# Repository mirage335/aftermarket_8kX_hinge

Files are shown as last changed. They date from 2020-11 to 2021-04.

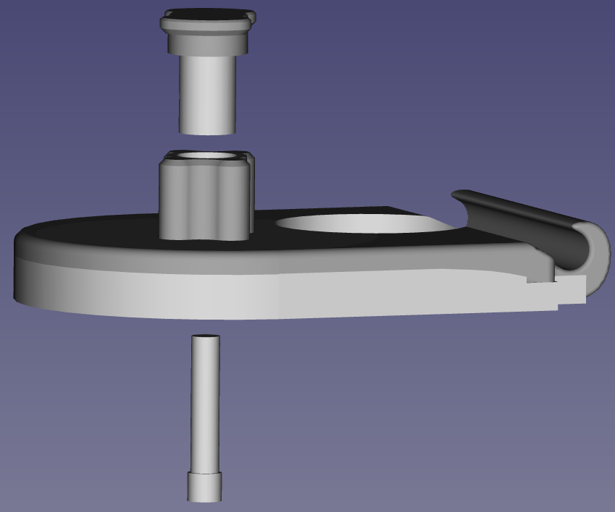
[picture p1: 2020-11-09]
_doc/parts-immovable.png

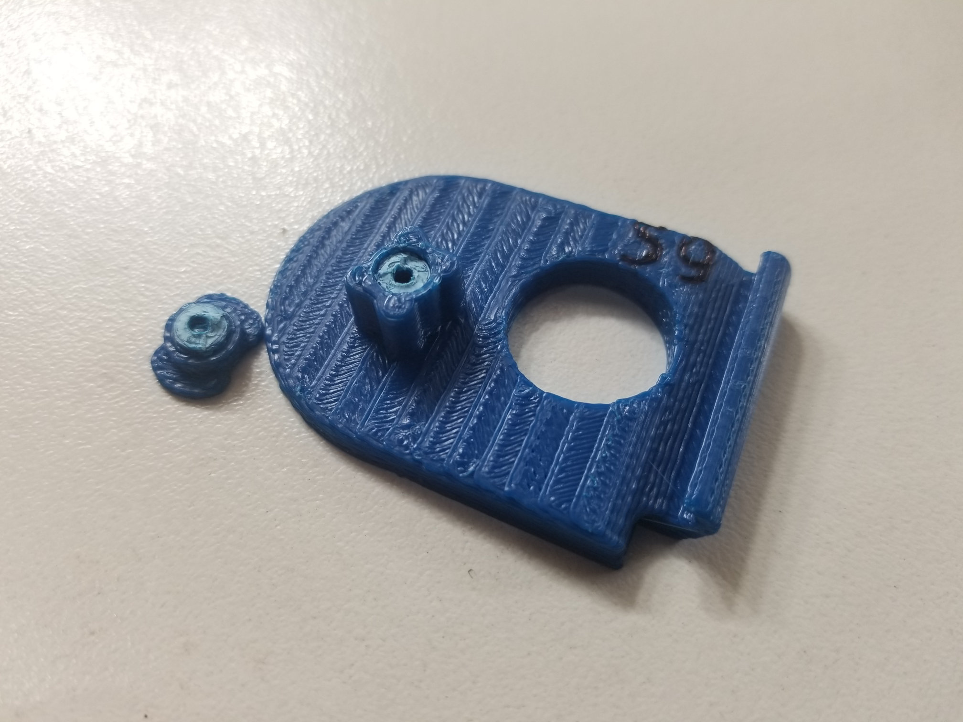
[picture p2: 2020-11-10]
_doc/manufacturing-example-failure-screwTooLong.jpg

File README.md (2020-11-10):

Copyright (C) 2020- mirage335
See the end of the file for license conditions.
See license.txt for aftermarket_8kX_hinge license conditions.

Aftermarket hinges to attach Pimax Vision 8kX to Modular Audio Strap, at angles different from those supplied by the original manufacturer Pimax. As a '3D printable' aftermarket modification, including derived third-party work under apparent GNU GPL v2 license, these alternative hinges are an independent offering.

Still, "mirage335" wishes to extend significant gratitude to Pimax, as well as the community established around Pimax, for the introduction of useful VR technology, that such aftermarket products are intended to further support.

# Usage

Be prepared to do some adjustment and experimentation.

Best fit may be obtained when most pressure from the VR headset is placed at the top of the comfort kit, and some, perhaps one-third, is placed closer to the nose.

As little as 1 degree may be the difference between substantial discomfort, or greatly increased usability during long VR sessions, particularly for simulation and CAD VR users.

Take care to ensure symmetric alignment - both left and right hinges should be at the same angles except in rare cases of the human user not being exactly bilaterally symmetric.

# Distribution

Consider providing end-users an entire copy of this repository with all submodules, in addition to PDF documents. Physical USB flash devices may be suitable for the repository, printed hardcopy may be suitable for the PDF documents.

All manufactured copies of this design should include at least a link to the source repository, regardless of legal requirements to do so.

# Design

Partly derived from a third-party CAD model, which documented correct geometric dimensions for the hinges used by the Pimax Vision 8kX and attached Modular Audio Strap. Portions of this prior CAD model are directly included in the 'legacy' design.

https://www.thingiverse.com/thing:4590303/files
http://www.gnu.org/licenses/old-licenses/gpl-2.0.html
https://github.com/pavel-ruban/Pimax
https://cad.onshape.com/documents/fc37eacb99e7b11e2a322105/w/a07aab2718f48f7bca448c96/e/941ae8a6d26472d6f4b638b7

User 'mirage335' is expected to have needed the MAS strap to lower to a somewhat further angle than most users - apporximately 159deg which may have been slightly lower due to 3D printing tolerance at the time. Consequently, angles useful to others are expected to fall between 157deg-161deg with possible outliers at 155deg (provided by Pimax plastic hinges) or 163deg (expected to be rarely desirable). Further experiments have shown these initial values may be 2deg less due to manufacturing tolerances of the original hinges that were printed vertically with detachable support.

Emboss font used is from '/usr/share/fonts/truetype/dejavu/DejaVuSansMono-Bold.ttf' (typical installed directory/file) , or similar, as specified in CAD model.

Angled (not flat) brackets may reduce screw length (from 12mm to 10mm or 8mm), reduce weight, improve adaptability (if flexible material), reduce plastic/material, reduce print time, and possibly add a small gap to improve compressibility under assembly screw pressure. Flat brackets may improve adjustability, improve repairability (better surfaces for gluing), increase layer adhesion, and reduce vibration during manufacturing (reducing wear on 3D printers). Beware estimates produced by slicing programs may underestimate print time, even after warmup.
Flat brackets, horizontal alignment, platter 10x, no pillar base, no pillar post...
* 90% Infill - 138% print time, 162% plastic
* 40% Infill - 116% print time, 135% plastic

Flat brackets, vertical alignment, platter 10x, no pillar base, no pillar post...
* 90% Infill - 153% print time, 175% plastic
* 40% Infill - 129% print time, 147% plastic

# Redistribution and Preservation

Entire 'recursive' clones of this repository with all submodules may be appropriate for redistribution and preservation.

# Safety

# FutureWork

# Reference

https://wiki.freecadweb.org/A2plus_Workbench
https://github.com/mirage335/freecad-assembly2

https://apps.dtic.mil/dtic/tr/fulltext/u2/a268661.pdf

https://www.fastenal.com/product/fasteners/screws/machine-screws/600059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
https://www.fastenal.com/product/fasteners/screws/machine-screws/600059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

https://community.openmr.ai/t/hinge-screws-standard-part-replacements/32489
https://groups.google.com/a/hacdc.org/g/blabber/c/DWuHq5YGobc

https://www.amazon.com/s?k=m2x40mm&i=tools&ref=nb_sb_noss

https://www.pocketscrewdrivers.com/Logo_Pocket_Screwdrivers_s/3.htm

# Directory Specification

Consider keeping a copy of this specification alongside relevant projects for reference.

Please regard as a loose specification intended to offer unallocated regions for expansion and subordinate to any improvements that may be found in actual implementations.

Projects which may be assembled into larger projects, if sufficiently well-developed, should include their own appropriate directories, rather than referencing files shared within larger projects. That is to say, a sort of 'static linking' approach is strongly recommended.

Numbered directories with '[z]-' in their prefix and a '/' may substitute the '/' for either a '-' or separate directories.

Numbered directories of top-directories may be placed alongside top-directories if desired. Numbering scheme is intended to minimize conflicts.

Templates should populate only the most usual directories. Not all directories need be populated for a project.

```

_lib	- software, records, etc, typically uniquely needed by specific CAD model

00[00]-RESERVED (do NOT use)

01[00]-Bundle
	0110-Frames
	0150-Actuators
	0151[z]-Thruster/Driver
		Components only used for these?
		Screws used within these?
	0160-Tools
		Nozzle
		Hot-End
		Cold-End
		Extension (Bowden Tube)
	0162-Supplementary
		Filament Storage
	0165-Slab (workpiece mounting surface)
	0170-Tray (surface to mount electronics and similar)
	0172-Rack (enclosure for electronics and similar, and/or junction box)
	0175-Cabinet (arbitrary storage)

11[00]-Structural (Passive, Cut To Size)
	1110[z]-Extrusions/Timbers
		_resized
	1112[z]-Sheets/Panels/Plates (for frames only)
		_rescaled (PreDrilled only)
	1115-Backing (Table)

30[00]-Conveyance
	3030[z]-Shaft/Piston
	3032-LeadScrew
	3033[z]-Belts
	3035- to 3038- RESERVED (do NOT use)

35[00]-Couplings (including flexible, u-joints, etc)
	3530-LeadScrew_to_Motor

50[00]-Effectors
	5050[z]-Motors/Steppers/Servos
	5051[z]-RotaryBearings/RotaryShims
	
	5052[z]-NutBlocks/PlatesEffectors/BracketsEffectors (typically belt tie-down points), etc.
	5053-RESERVED
	
	5054[z]-Guides (Wheels/Bushings/LinearBearings)
	
	5055-Pulleys
	5056-Gears
	
	5058-Limit Switch

55[00]-RESERVED (do NOT use)

(6000 RESERVED)

(7000 RESERVED)

80[00]-Endpoints
	8080-Plug
		RJ45
		misc
	8081-Jack
		RJ45
		misc
	8082-RESERVED (do NOT use)
	8083-RESERVED (do NOT use)

85[00]-Dissipator
	8580-Fans
	8581-Pump
	8582-Heatsink
	8585-Radiator

9000-Miscellaneous
	9090z-Screws/Bolts
	9095-frequent (most frequently used)
	9099-Misc
		zMisc (unsortred, typically uniquely needed by specific CAD model)

9100-KEEPOUT (solid objects used to mark regions reserved for future use)

94[00]
to
98[00]
	RESERVED for future use

99[00]-import
	RESERVED for future use

```

# Manufacturing

Recommended 3D printer 'slicer' settings...

* No 'Brim'.
* Solid infill threshold area >70mm^2 .
* >45% Fill, 'Rectilinear'
* <0.3mm Layer Height
* <0.5mm Extrusion Width
* 2 'vertical shells', 2 'horizontal shells'
* disable 'external perimeters first'

* >50% Infill/perimeters overlap

* <0.25mm or 0mm XY Size Compensation
* 0mm (full) 'Resolution'

* 3mm extruder
* 240mm/s travel speed
* 85mm/s print speed
* 65mm/s 'gap fill'

* disable 'complete individual objects'

Occasionally one overhanging perimeter may sag down from the hinge inner surface. Such a perimeter should be removed with tweezers, more than one such sagging perimeter line may be cause to consider the print a failure.

The pillar post and pillar base should easily fit together, and should not be tightened until held in place by screw and/or glue.

A vise may be used during screw tightening to ensure correct alignment. Screw should be tight enough to prevent rotation of the pillar post - this tightening will also ensure the pillar base does not separate from the underlying bracket when under pressure.

An M2.5 or M2 screw, length 12mm, 10mm, or 8mm, should be used to join pillar post and pillar base. Phillips head is specifically strongly discouraged. M2x8mm has been proven workable for the angled hinges. M2x10mm has been proven workable for the flat hinges.

Flexible material - such as NinjaFlex - may be able to maintain desired pressure towards the top of the head - with a wider variety of geometries and pressures. This has not been tested.

# Hinge Pins

Apparently these are 'headless shoulder bolts' or 'threaded link band screw' - perhaps M1/M2/M2.5 diameter/thread , 30mm shoulder length , 35mm total length . Despite some effort and progress in determining possible sources for these visibly standards resembling screws, at least their length seems to be unusual.

Heat shrink tubing around more typical M1/M2/M2.5x40mm screws may be a practical workaround.

# Third-Party Copyright Notices

Third-Party copyrights are noted within text files alongside directories containing the original files, and/or within text files alongside directories containing the modified files, and/or within version control commit history.

Some copyright licenses have specific requirements, and some authors have specific requests, to prominently display copyright notices - these are included here.

However, the manner some or all of these third-party files are used may in fact be fair use, in which case the third-party licenses would not in fact have any effect on the license requirements for the otherwise possibly derivative project.

While other files in the 'aftermarket_8kX_hinge' may, as stated, be redistributed under GNU GPL license versions later than version 2, all files derived from (or otherwise including) third party files obtained under apparent GNU GPL v2 license, must retain that license.

# Copyright

This file is part of aftermarket_8kX_hinge.

aftermarket_8kX_hinge is free software: you can redistribute it and/or modify
it under the terms of the GNU General Public License as published by
the Free Software Foundation, either version 2 of the License, or
(at your option) any later version.

aftermarket_8kX_hinge is distributed in the hope that it will be useful,
but WITHOUT ANY WARRANTY; without even the implied warranty of
MERCHANTABILITY or FITNESS FOR A PARTICULAR PURPOSE.  See the
GNU General Public License for more details.

You should have received a copy of the GNU General Public License
along with aftermarket_8kX_hinge.  If not, see <http://www.gnu.org/licenses/>.

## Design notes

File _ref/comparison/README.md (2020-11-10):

A relatively small angular difference (~155deg vs ~161deg) allows approximately 12cm additional travel distance.

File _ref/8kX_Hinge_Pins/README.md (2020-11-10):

Metal hinge pins used by the Pimax 8kX resemble standard 'headless shoulder bolts', which may also resemble 'threaded link band screw' .

M1.6 ? #0 (0.060in, 1/16in) ? M1.4 ?

37mm? 1.46in? 1-7/16in?

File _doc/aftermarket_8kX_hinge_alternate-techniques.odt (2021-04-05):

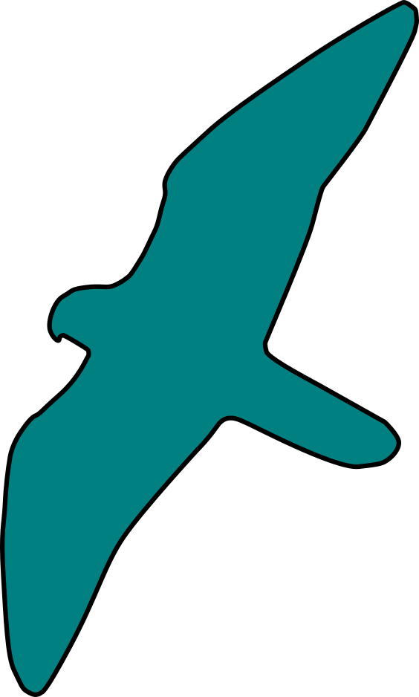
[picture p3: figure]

# aftermarket_8kX_hinge

Production and Development associated with...

3D Connected Printing, Soaring Industries LLC, "mirage335"

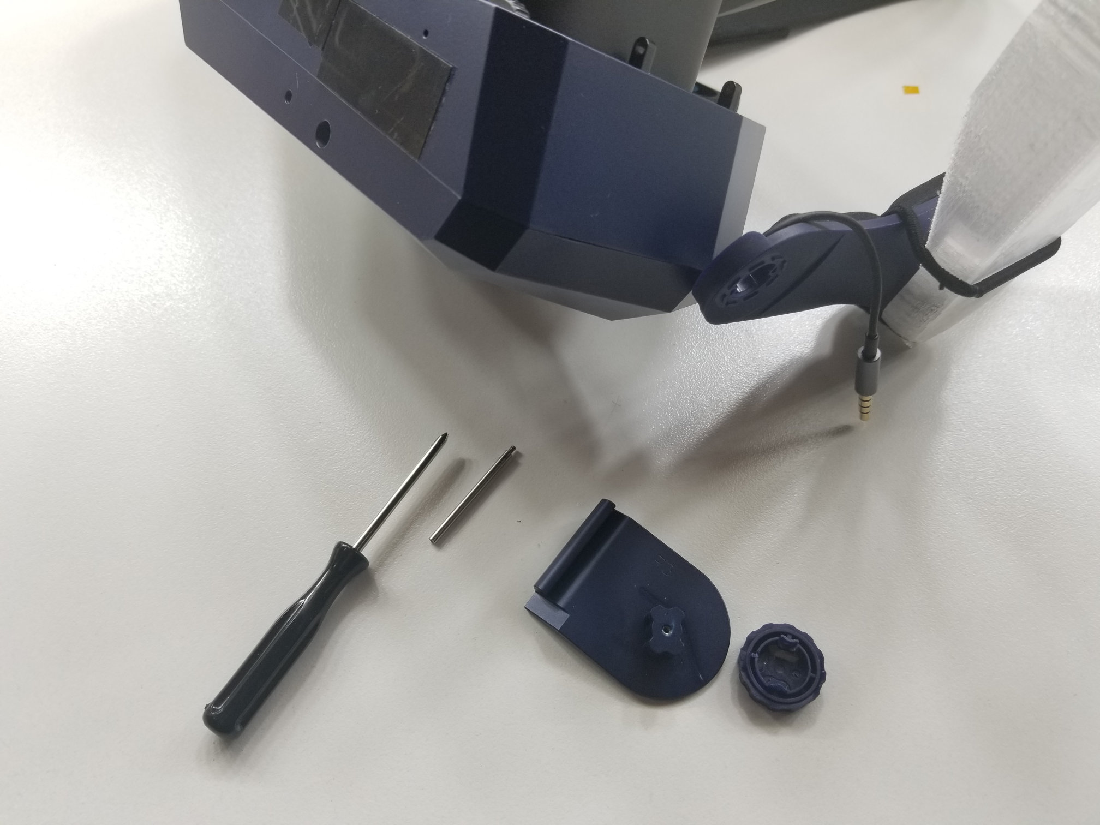
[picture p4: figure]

Aftermarket hinges to attach Pimax Vision 8kX to Modular Audio Strap, at angles different from those supplied by the original manufacturer Pimax. As a '3D printable' aftermarket modification, including derived third-party work under apparent GNU GPL v2 license, these alternative hinges are an independent offering.

Alternate Installation Technique

Physically pulling out the large rubber black cowling may allow the hinges to be gently rotated onto the hinge pins without removing them. Reportedly, this may be much easier than trying to slide the hinge pins into the hinges later as would otherwise be necessary.

We appreciate your patience as we continue investigating and documenting.

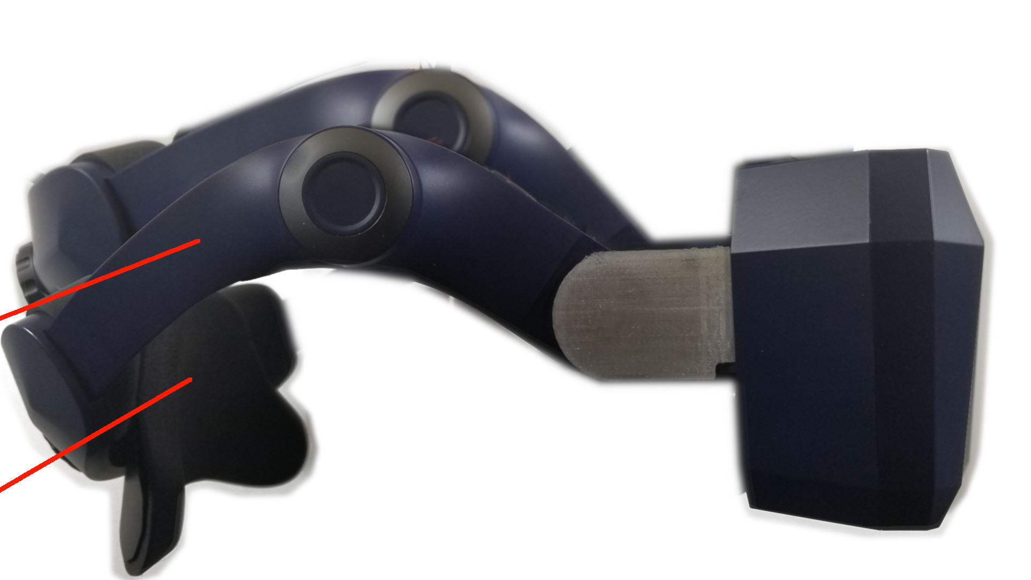
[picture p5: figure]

Do NOT Pick Up from Side

Please do NOT grab headset from just one side of strap. Always grab from top strap, headset itself, or any other balanced location.

Lifting the headset from the side strap will apply a torsion mechanical load which stresses the hinges far beyond any forces encountered in normal use. Although some hinges may show soldering iron wedge tip marks made to improve adhesion, the confined space does NOT allow us to add sufficient material to prevent such breakage. Also, spare 161deg hinge pairs may be shipped with larger orders to ensure customer success.


Please be aware of this limitation.

We appreciate your patience as we continue investigating and documenting.

Third-Party Copyright Notices - Particularly important CAD models in this 'aftermarket_8kX_hinge' are derived from dimensionally accurate CAD models provided by 'OpenMR' forum participant 'Teigue'.
https://www.thingiverse.com/thing:4590303/files
http://www.gnu.org/licenses/old-licenses/gpl-2.0.html
https://github.com/pavel-ruban/Pimax
https://cad.onshape.com/documents/fc37eacb99e7b11e2a322105/w/a07aab2718f48f7bca448c96/e/941ae8a6d26472d6f4b638b7
https://github.com/mirage335/aftermarket_8kX_hinge/tree/main/_ref/8kX_SMAS%20Hinge-thirdParty

While other files in the 'aftermarket_8kX_hinge' may, as stated, be redistributed under GNU GPL license versions later than version 2, all files derived from (or otherwise including) third party files obtained under apparent GNU GPL v2 license, must retain that license.

Copyright - Copyright (C) 2020- mirage335
This file is part of aftermarket_8kX_hinge.
aftermarket_8kX_hinge is free software: you can redistribute it and/or modify it under the terms of the GNU General Public License as published by the Free Software Foundation, either version 2 of the License, or (at your option) any later version.
aftermarket_8kX_hinge is distributed in the hope that it will be useful, but WITHOUT ANY WARRANTY; without even the implied warranty of MERCHANTABILITY or FITNESS FOR A PARTICULAR PURPOSE. See the GNU General Public License for more details.
You should have received a copy of the GNU General Public License along with aftermarket_8kX_hinge. If not, see <http://www.gnu.org/licenses/>.
VIDEO TUTORIAL https://www.youtube.com/watch?v=DQY9Z6OXVtY (https://www.youtube.com/watch?v=DQY9Z6OXVtY) https://github.com/mirage335/aftermarket_8kX_hinge (https://github.com/mirage335/zipTiePanel)
https://3dconnectedprinting.com https://www.etsy.com/shop/3DConnectedPrinting https://community.openmr.ai/

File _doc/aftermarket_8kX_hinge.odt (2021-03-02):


# aftermarket_8kX_hinge

Production and Development associated with...

3D Connected Printing, Soaring Industries LLC, "mirage335"

Aftermarket hinges to attach Pimax Vision 8kX to Modular Audio Strap, at angles different from those supplied by the original manufacturer Pimax. As a '3D printable' aftermarket modification, including derived third-party work under apparent GNU GPL v2 license, these alternative hinges are an independent offering.

Tools


A small Phillips screwdriver, and possibly a small standard (flat) screwdriver, will be required. Typical, widely available, multi-tip 'precision' screwdriver kits, include appropriately sized bits. Please be careful not to allow the Phillips driver/screw to 'cam out', as this may make the screw difficult to remove in the future.

Installation

To remove old hinge, gently unscrew metal hinge pins, and gently twist off locking plastic cap. Attach new hinge using same metal hinge pins and locking plastic cap. Carefully avoid pinching wires.


Angle

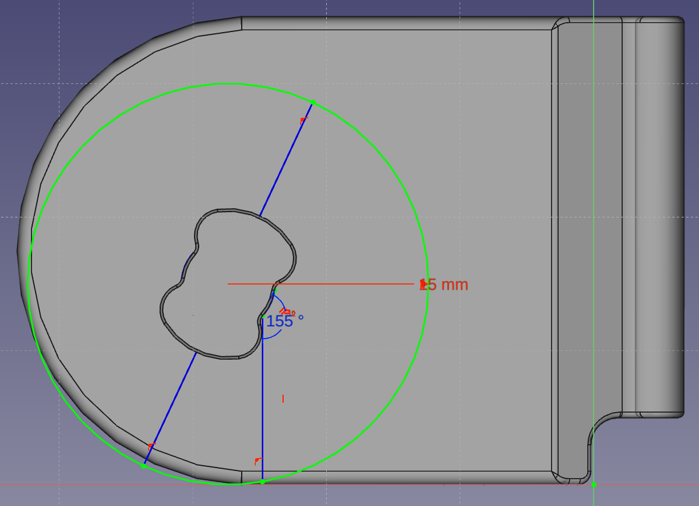
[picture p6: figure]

How far the strap can bend down before tilting the headset up is determined by the angle of the 'pillar base' on the hinge.

An angle of 161deg is recommended as a starting point. Lower numbers of degrees will reduce pressure on cheekbones, higher numbers will spread pressure more evenly across the entire face. Plastic hinges shipped by Pimax have been known to use an approximately 155deg angle.

Immovable vs Adjustable vs Flexible


Immovable

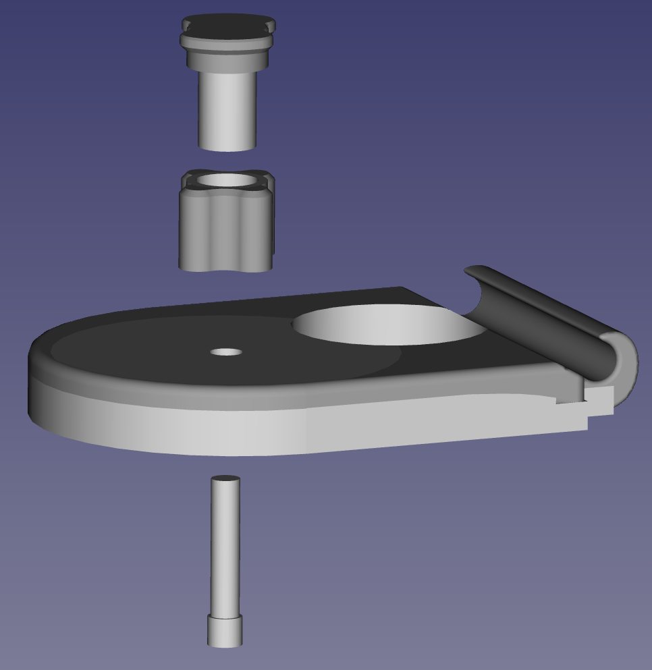
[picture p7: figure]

Adjustable

Immovable hinges have pillar bases permanently attached to the hinges at manufacturing. Hinges are swapped (removed and replaced completely by new hinge) to change angle.

Adjustable hinges are manufactured as separate parts, allowing the pillar base angle to be changed while loosened. Adjustable hinges may require epoxy and careful measurements to prevent undesired rotation or tilt.

Flexible hinges are usually immovable hinges made of flexible material.

Third-Party Copyright Notices - Particularly important CAD models in this 'aftermarket_8kX_hinge' are derived from dimensionally accurate CAD models provided by 'OpenMR' forum participant 'Teigue'.
https://www.thingiverse.com/thing:4590303/files
http://www.gnu.org/licenses/old-licenses/gpl-2.0.html
https://github.com/pavel-ruban/Pimax
https://cad.onshape.com/documents/fc37eacb99e7b11e2a322105/w/a07aab2718f48f7bca448c96/e/941ae8a6d26472d6f4b638b7
https://github.com/mirage335/aftermarket_8kX_hinge/tree/main/_ref/8kX_SMAS%20Hinge-thirdParty

While other files in the 'aftermarket_8kX_hinge' may, as stated, be redistributed under GNU GPL license versions later than version 2, all files derived from (or otherwise including) third party files obtained under apparent GNU GPL v2 license, must retain that license.

Copyright - Copyright (C) 2020- mirage335
This file is part of aftermarket_8kX_hinge.
aftermarket_8kX_hinge is free software: you can redistribute it and/or modify it under the terms of the GNU General Public License as published by the Free Software Foundation, either version 2 of the License, or (at your option) any later version.
aftermarket_8kX_hinge is distributed in the hope that it will be useful, but WITHOUT ANY WARRANTY; without even the implied warranty of MERCHANTABILITY or FITNESS FOR A PARTICULAR PURPOSE. See the GNU General Public License for more details.
You should have received a copy of the GNU General Public License along with aftermarket_8kX_hinge. If not, see <http://www.gnu.org/licenses/>.
VIDEO TUTORIAL https://www.youtube.com/watch?v=DQY9Z6OXVtY (https://www.youtube.com/watch?v=DQY9Z6OXVtY) https://github.com/mirage335/aftermarket_8kX_hinge (https://github.com/mirage335/zipTiePanel)
https://3dconnectedprinting.com https://www.etsy.com/shop/3DConnectedPrinting https://community.openmr.ai/

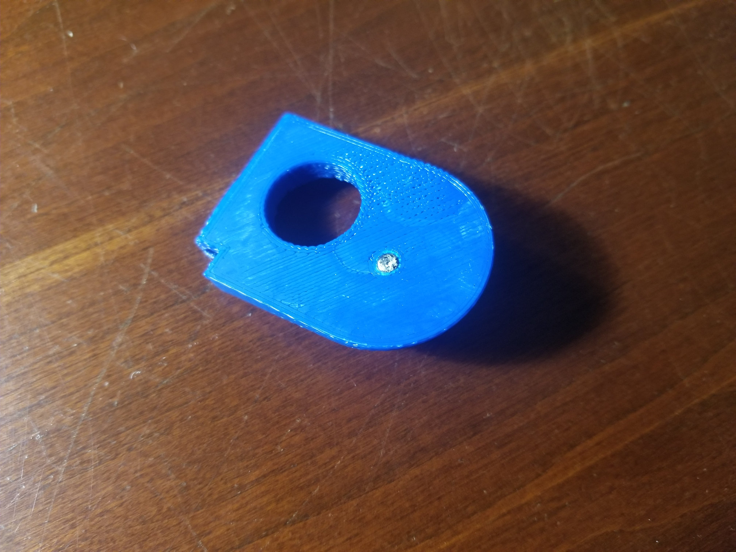
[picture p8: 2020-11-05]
Photo-Back.jpg

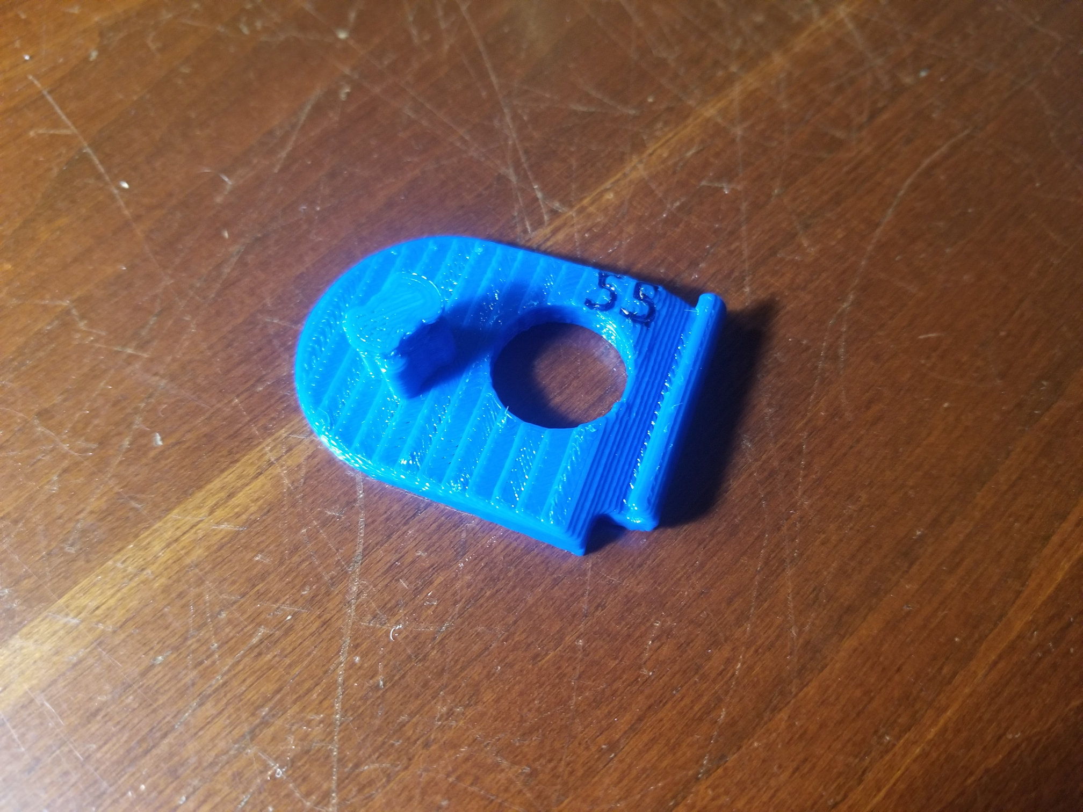
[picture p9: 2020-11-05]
Photo-Front.jpg

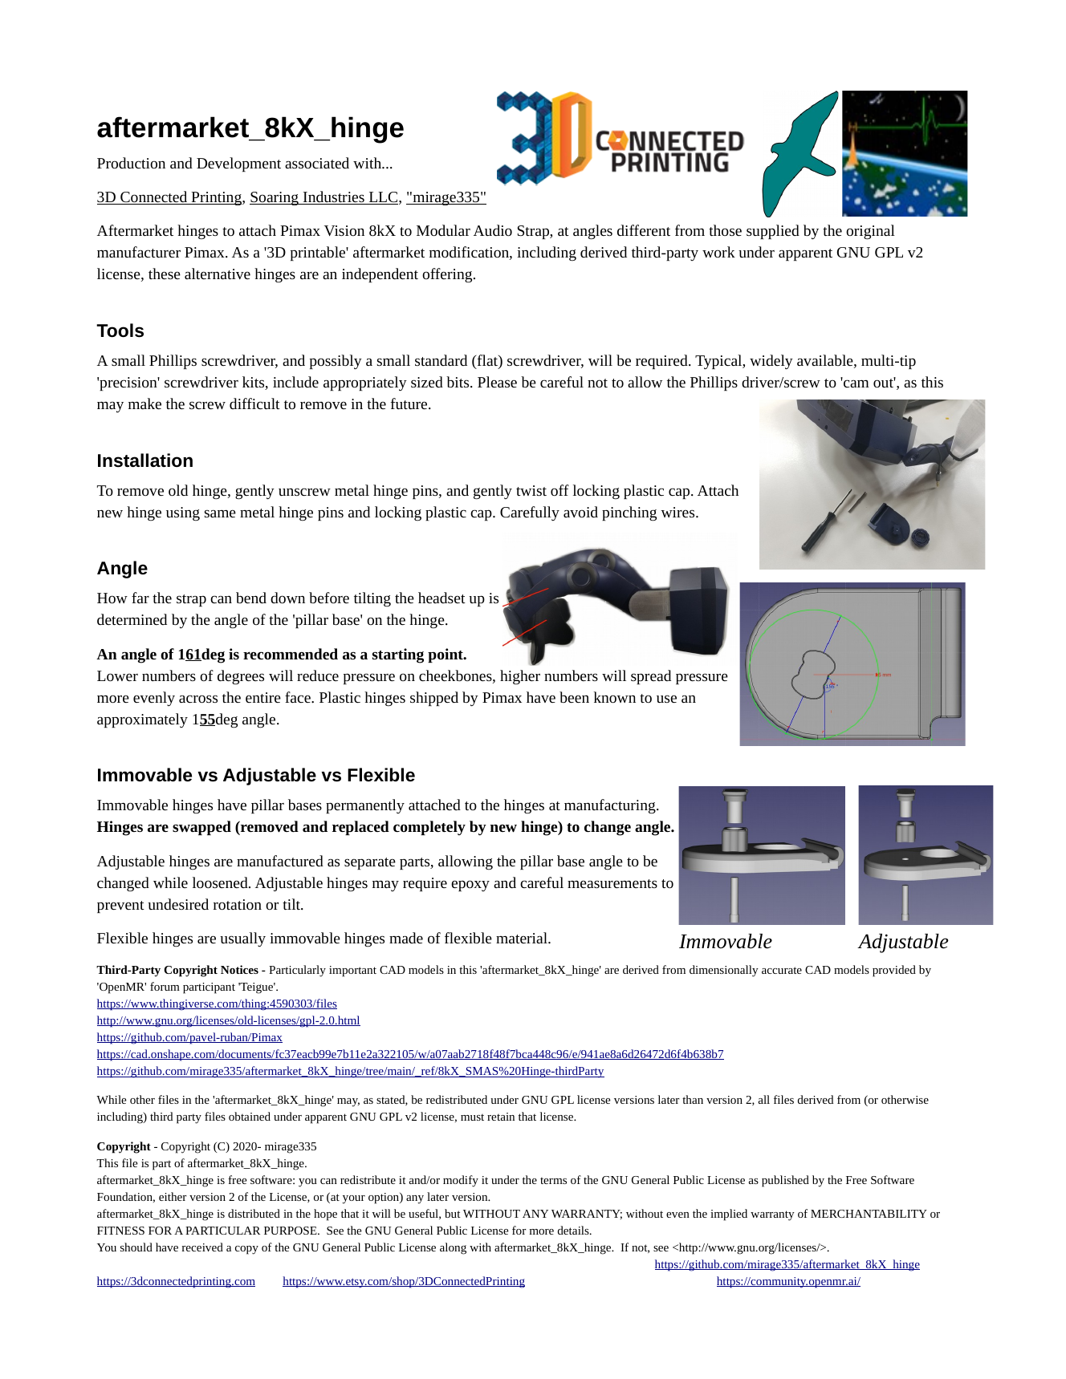
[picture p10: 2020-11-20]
_doc/aftermarket_8kX_hinge.png

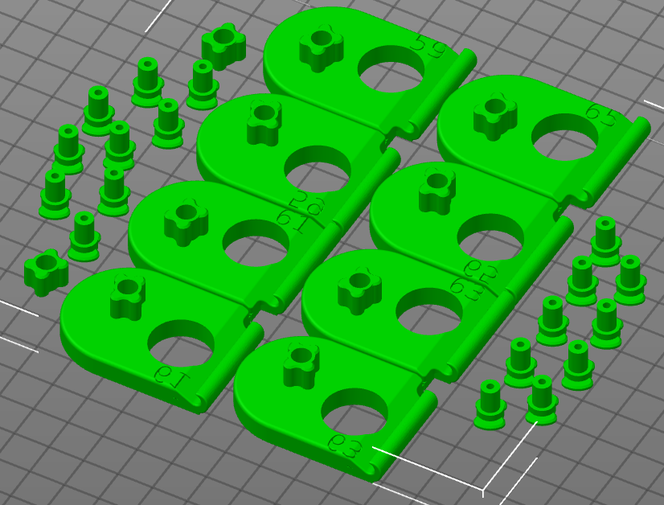
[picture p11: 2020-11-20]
platter-essential.png

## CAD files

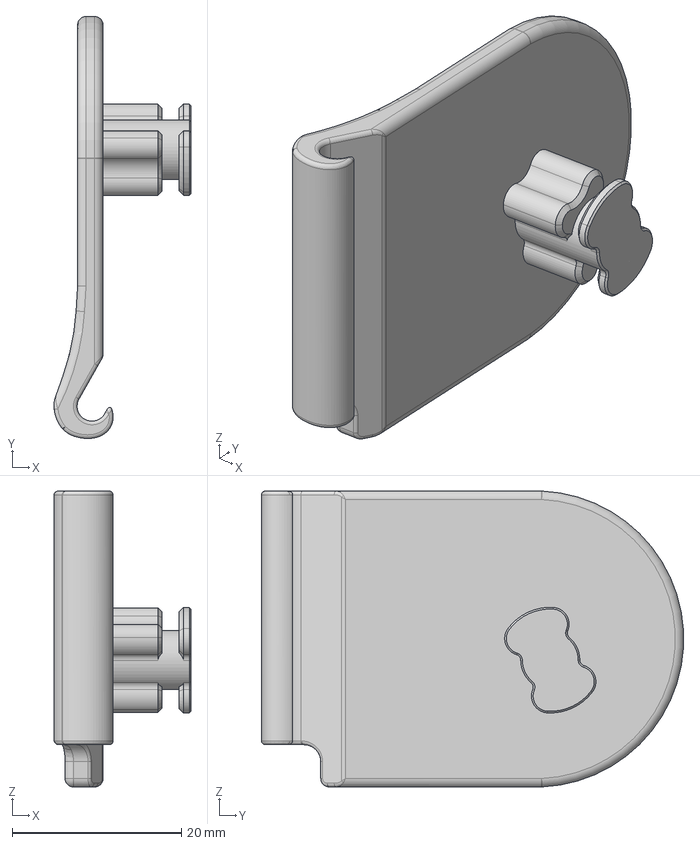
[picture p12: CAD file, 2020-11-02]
_ref/8kX_SMAS Hinge-thirdParty/mod/8KX - SMAS Hinge - Right - Metal.step
16.2 x 49.9 x 35.0 mm

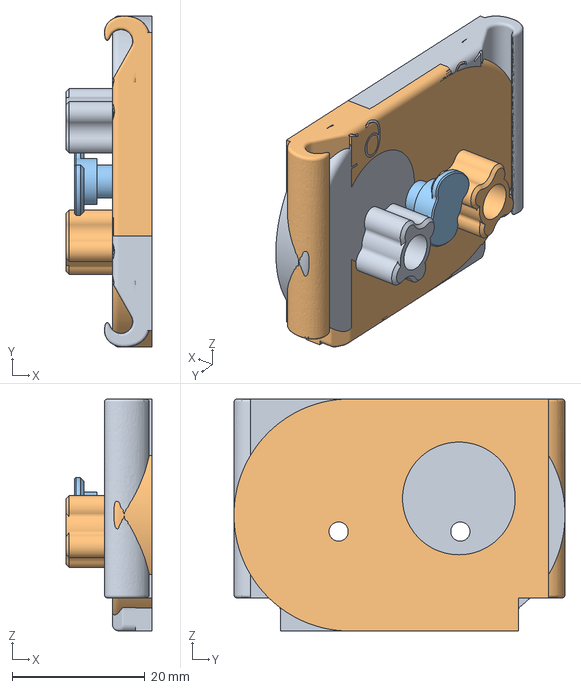
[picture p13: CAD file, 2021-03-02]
platter-161deg-3x.zip.amf
13.0 x 50.0 x 35.0 mm
pillar-base_001 x 2

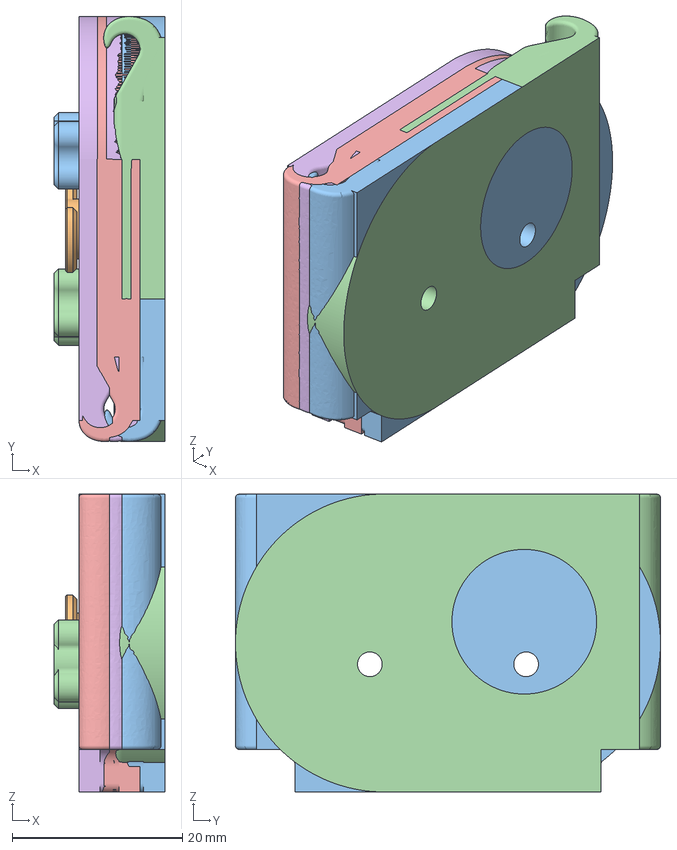
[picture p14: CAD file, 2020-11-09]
platter-adjustable.zip.amf
13.0 x 50.0 x 35.0 mm
pillar-base_001 x 2

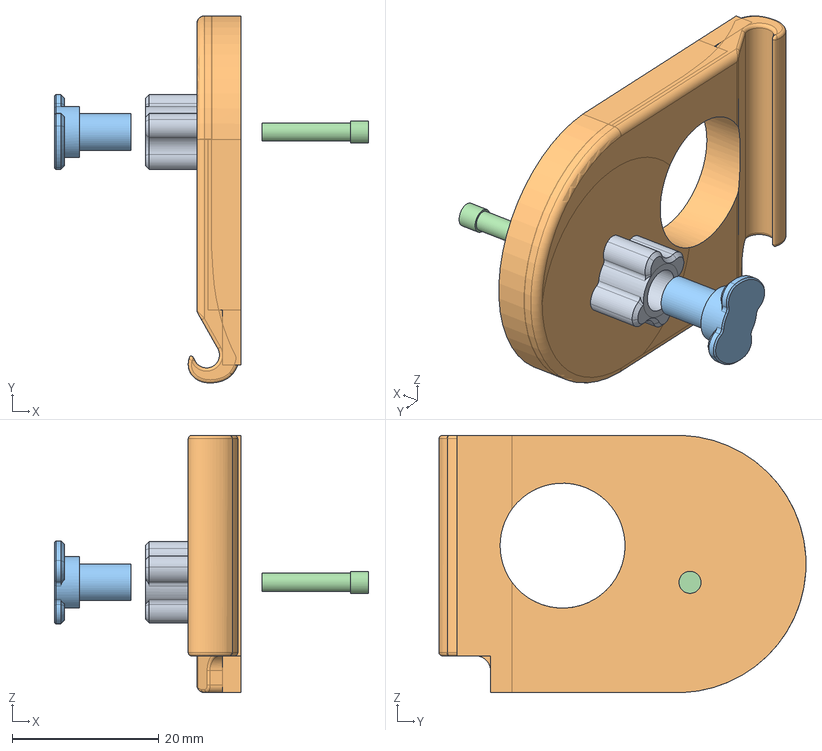
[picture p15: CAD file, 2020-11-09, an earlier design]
legacy/_ref/hinge-left-155deg-flat-measurements.FCStd
42.8 x 49.9 x 35.0 mm
pillar-base_001
bracket-left-flat_001
pillar-post_001
M2.5x12mm-worstCase_001

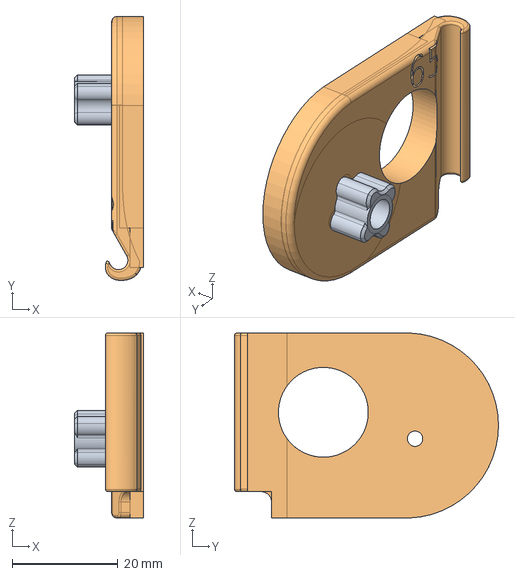
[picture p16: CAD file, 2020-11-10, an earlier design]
legacy/hinge-left-165deg-flat.fcstd
13.0 x 50.0 x 35.0 mm
pillar-base_001

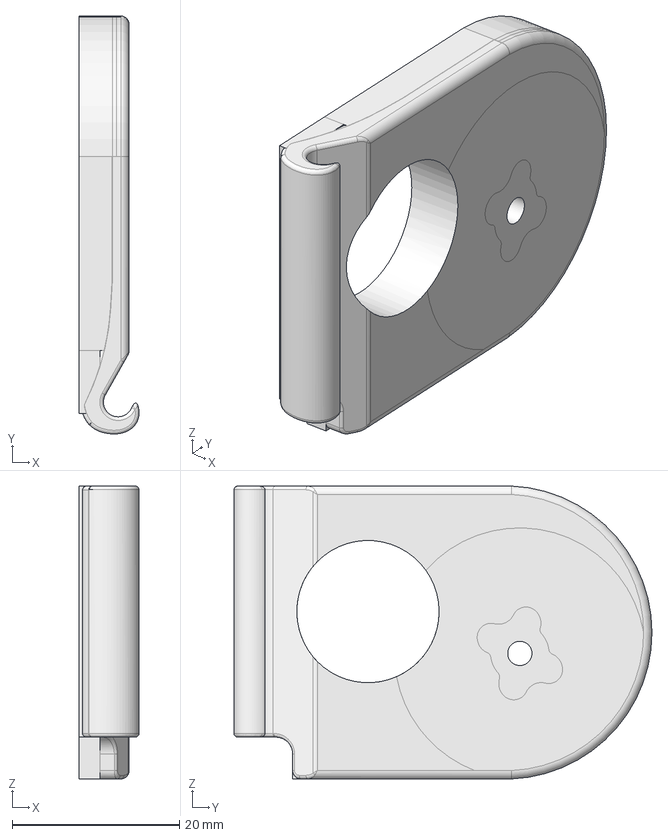
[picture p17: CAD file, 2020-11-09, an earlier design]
legacy/parts/bracket-right-flat.fcstd
7.19 x 50.0 x 35.0 mm

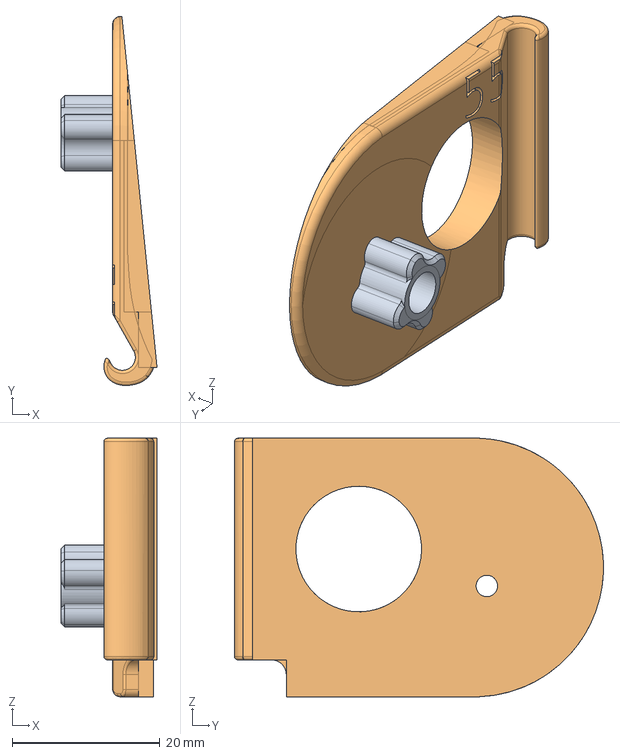
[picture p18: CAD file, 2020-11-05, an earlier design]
legacy/_ref/hinge-left-155deg-angled-measurements.fcstd
13.0 x 50.0 x 35.0 mm
pillar-base_001

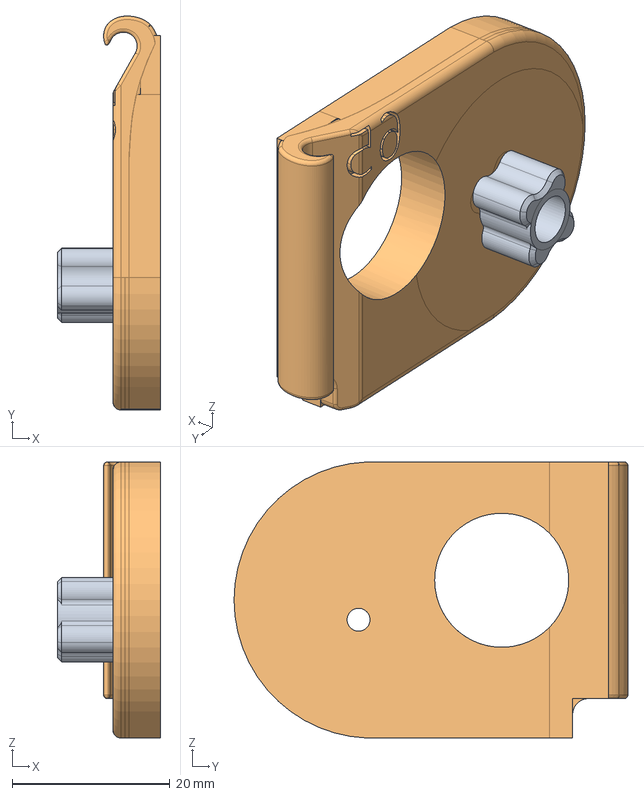
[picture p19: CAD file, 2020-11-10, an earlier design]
legacy/hinge-right-165deg-flat.fcstd
13.0 x 50.0 x 35.0 mm
pillar-base_001

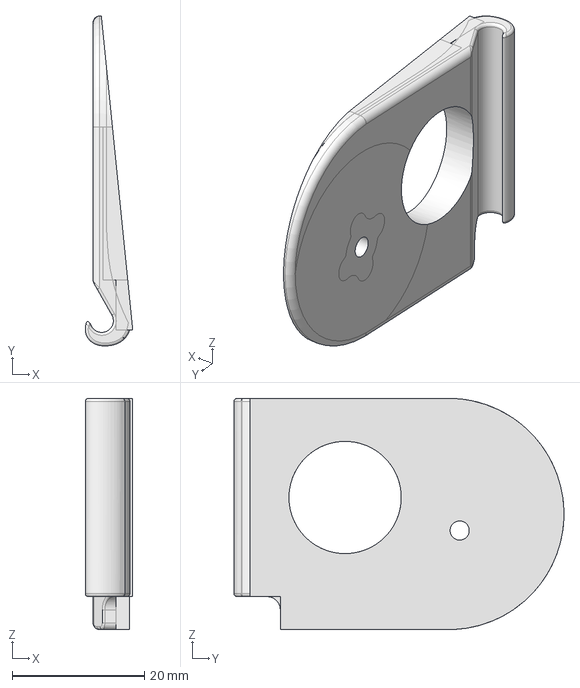
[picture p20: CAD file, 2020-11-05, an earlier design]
legacy/parts/bracket-left-angled.fcstd
7.19 x 50.0 x 35.0 mm

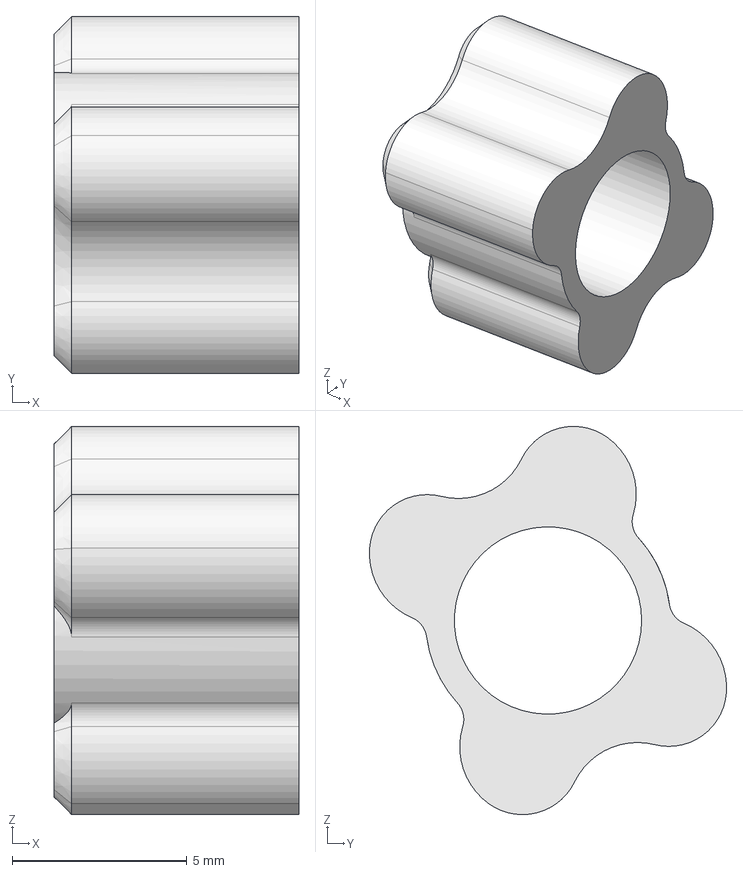
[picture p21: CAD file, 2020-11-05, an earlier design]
legacy/parts/pillar-base.fcstd
7.00 x 10.2 x 11.1 mm

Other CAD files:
_ref/8kX_SMAS Hinge-thirdParty/mod/8KX - SMAS Hinge - Left - Plastic.step
platter-161deg.zip.amf
_ref/8kX_SMAS Hinge-thirdParty/mod/8KX - SMAS Hinge - Left - Metal.step
_ref/8kX_SMAS Hinge-thirdParty/mod/8KX - SMAS Hinge - Right - Plastic.step
legacy/hinge-left-157deg-flat.fcstd
legacy/parts/bracket-right-angled.fcstd
legacy/hinge-right-159deg-flat.fcstd
legacy/hinge-right-170deg-flat.fcstd
legacy/_export/bracket-left-angled.amf
legacy/_export/bracket-left-angled.stl
legacy/_export/bracket-left-flat.amf
legacy/_export/bracket-left-flat.stl
legacy/_export/bracket-right-angled.amf
legacy/_export/bracket-right-angled.stl
legacy/_export/bracket-right-flat.amf
legacy/_export/bracket-right-flat.stl
legacy/_export/hinge-left-155deg-angled.amf
legacy/_export/hinge-left-155deg-angled.stl
legacy/_export/hinge-left-155deg-flat.amf
legacy/_export/hinge-left-155deg-flat.stl
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

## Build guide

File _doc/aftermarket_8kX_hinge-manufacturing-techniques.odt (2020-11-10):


# aftermarket_8kX_hinge

Production and Development associated with...

3D Connected Printing, Soaring Industries LLC, "mirage335"


Aftermarket hinges to attach Pimax Vision 8kX to Modular Audio Strap, at angles different from those supplied by the original manufacturer Pimax. As a '3D printable' aftermarket modification, including derived third-party work under apparent GNU GPL v2 license, these alternative hinges are an independent offering.

Copyright (C) 2020- mirage335
See the end of the file for license conditions.
See license.txt for aftermarket_8kX_hinge license conditions.

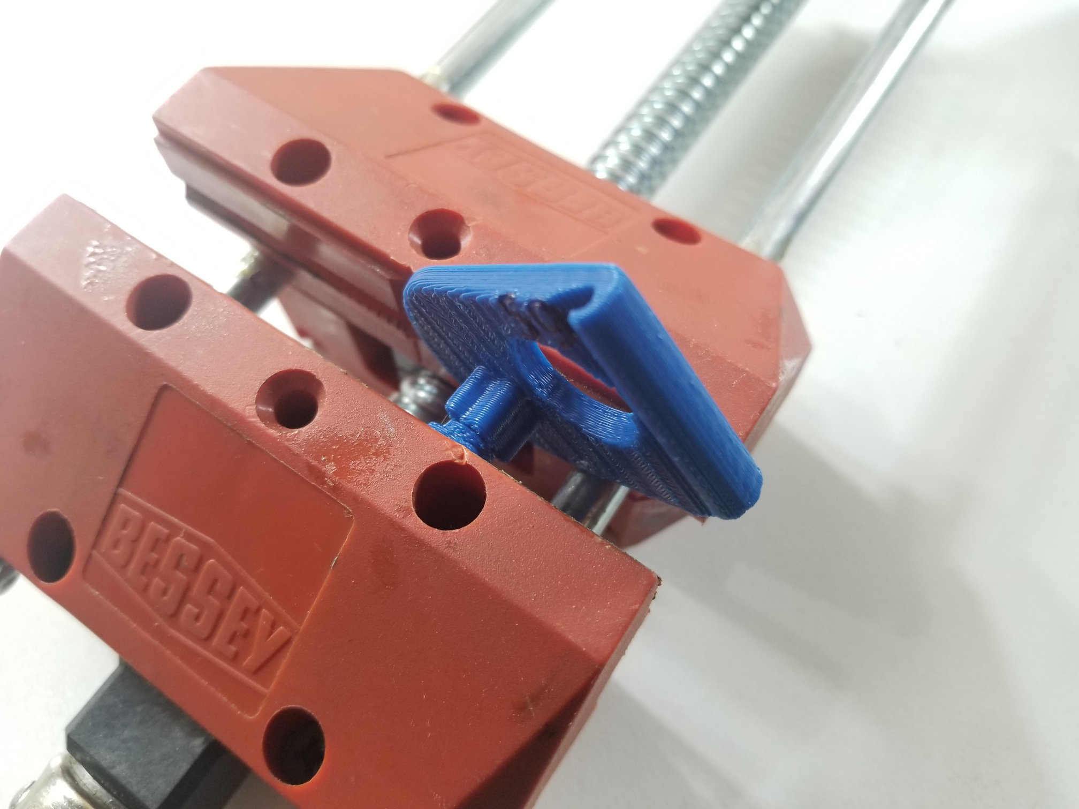
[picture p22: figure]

Post to Base

If 'XY compensation' is used, the post may loosely fit in the base. Otherwise, these parts are likely to fit together tightly enough to require a vise to completely push together. Carefully avoid any off-axis force to prevent damage. Reject any parts that noticeably crack during this process.

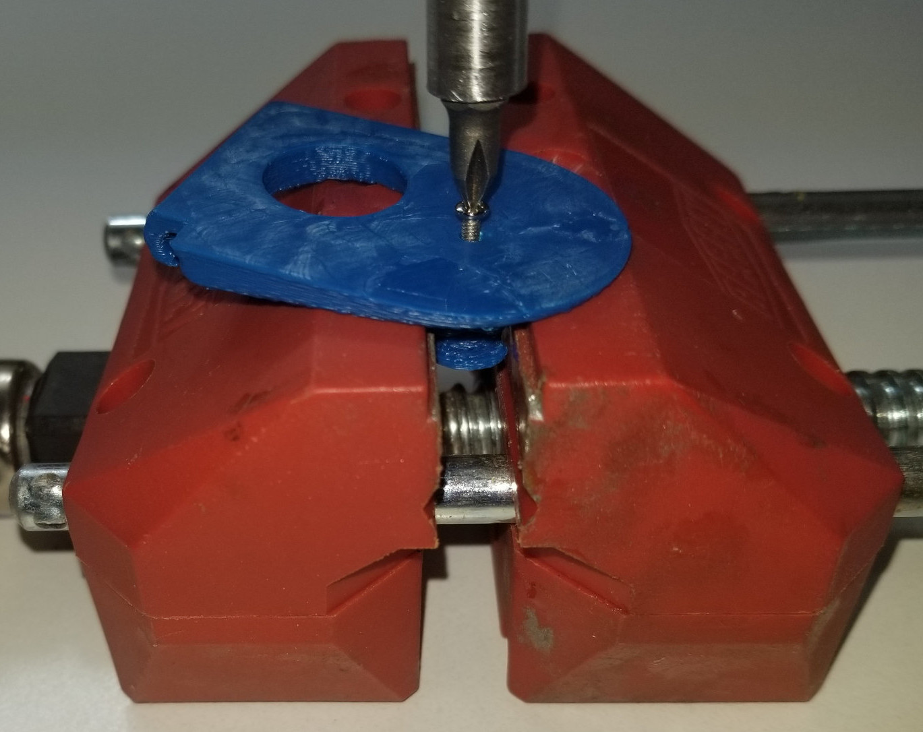
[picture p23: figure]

Post Rotational Alignment and Screw Tightening

While turning the screw to fasten the post to the base, the post may rotate. A vise may be used to constrain this undesired movement, preventing misalignment.

Only tighten the screw as necessary to completely pull together the post to base, or for the screw head to meet the plastic surface. Do not attempt to overdrive.

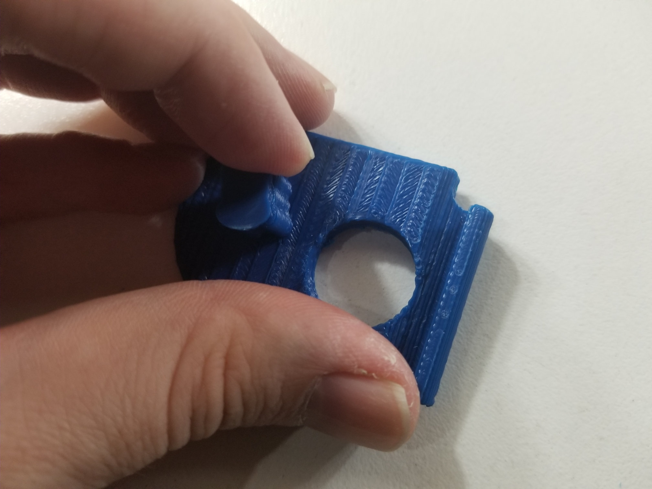
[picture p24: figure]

Post Must Be Finger Tight

Once post is fastened to the base with a screw, the post must not rotate under the amount of pressure that could reasonably be applied by a typical human finger. That is to say it must be 'finger tight'.

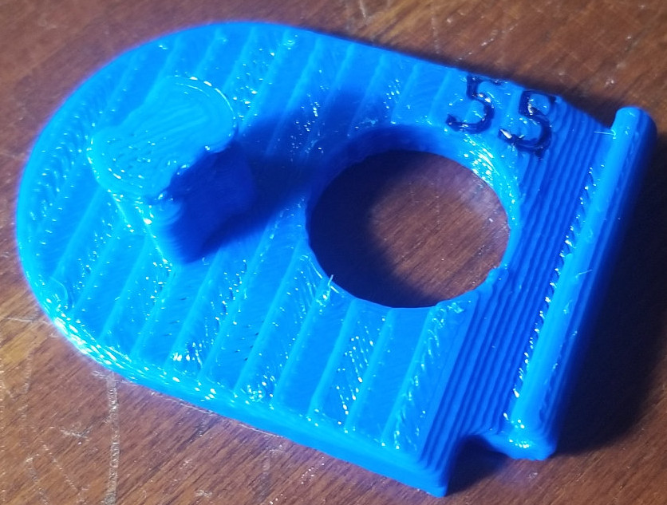
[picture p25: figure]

Matching Hinges and Number Readability

Identical angle hinges must be used for both left and right - if a 155deg hinge is used for the left, then a 155deg hinge must be used for the right. Mismatching these hinges will result in a subtle cause of discomfort for the end-user.

To minimize the risk of such mismatch, models may include numeric labels. These labels need not be clearly readable, but it is useful if they appear somewhat unique. Particularly important labels likely to be a starting point for most users - 155deg (shown here) or 161deg - may be further marked by running a permanent marker or perhaps paint along the resulting channel.

In addition, it may be helpful to place each pair of hinges in clear plastic bags.

Third-Party Copyright Notices - Particularly important CAD models in this 'aftermarket_8kX_hinge' are derived from dimensionally accurate CAD models provided by 'OpenMR' forum participant 'Teigue'.
https://www.thingiverse.com/thing:4590303/files
http://www.gnu.org/licenses/old-licenses/gpl-2.0.html
https://github.com/pavel-ruban/Pimax
https://cad.onshape.com/documents/fc37eacb99e7b11e2a322105/w/a07aab2718f48f7bca448c96/e/941ae8a6d26472d6f4b638b7
https://github.com/mirage335/aftermarket_8kX_hinge/tree/main/_ref/8kX_SMAS%20Hinge-thirdParty

While other files in the 'aftermarket_8kX_hinge' may, as stated, be redistributed under GNU GPL license versions later than version 2, all files derived from (or otherwise including) third party files obtained under apparent GNU GPL v2 license, must retain that license.

Copyright - Copyright (C) 2020- mirage335
This file is part of aftermarket_8kX_hinge.
aftermarket_8kX_hinge is free software: you can redistribute it and/or modify it under the terms of the GNU General Public License as published by the Free Software Foundation, either version 2 of the License, or (at your option) any later version.
aftermarket_8kX_hinge is distributed in the hope that it will be useful, but WITHOUT ANY WARRANTY; without even the implied warranty of MERCHANTABILITY or FITNESS FOR A PARTICULAR PURPOSE. See the GNU General Public License for more details.
You should have received a copy of the GNU General Public License along with aftermarket_8kX_hinge. If not, see <http://www.gnu.org/licenses/>.
https://github.com/mirage335/aftermarket_8kX_hinge (https://github.com/mirage335/zipTiePanel)
https://3dconnectedprinting.com https://www.etsy.com/shop/3DConnectedPrinting

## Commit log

2020-11-05 STL files.
    [hinge-left-159deg-flat.stl, hinge-left-159deg.stl]
2020-11-09 Many different angles. Exported models for manufacturing.
    [bracket-left-angled.amf, bracket-left-angled.stl, bracket-left-flat.amf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]
2021-01-26 Dedicated platter of 161deg hinges.
    [platter-161deg.zip.amf]
